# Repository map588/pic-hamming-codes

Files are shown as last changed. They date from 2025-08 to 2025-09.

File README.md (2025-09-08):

# PIC Parity Bit Error Detection Game

A PIC16F818 microcontroller-based educational game that teaches error detection using Hamming code parity bits through an interactive LED matrix display.

## Project Overview

This project implements a 4x4 LED grid game where players must identify and correct single-bit errors in transmitted data using parity bits. The system displays random data with intentional errors, and players use buttons to select and correct the flipped bit. 

I was inspired to make the project by [this excellant video](https://youtu.be/wTJI_WuZSwE?si=To3kZnW4QarjRsSB) by 3Blue1Brown on youtube.  Its really good, you should go watch it, its way better than my boring assembly code. 

### Key Features
- 4x4 LED matrix displaying random data patterns
- 4 parity bit indicators showing error detection codes
- Interactive button controls for bit selection and confirmation
- Visual feedback for correct/incorrect solutions
- Random number generation for varied gameplay

## Game Mechanics

1. **Display**: A 4x4 grid shows random on/off LEDs representing transmitted data
2. **Parity Bits**: 4 LEDs indicate parity for different bit groupings:
   - Bit 0: Columns 1 and 3 parity
   - Bit 1: Columns 2 and 4 parity  
   - Bit 2: Rows 1 and 3 parity
   - Bit 3: Rows 2 and 4 parity
3. **Objective**: Identify which bit in the 4x4 grid has been flipped
4. **Controls**:
   - Selection button: Cycle through grid positions (current selection blinks)
   - Confirm button: Lock in selection and check answer
   - Reset button: Generate new puzzle

### Feedback System
- **Correct Answer**: Diagonal checkmark animation on grid, all parity bits flash
- **Wrong Answer**: X pattern on grid, parity bits alternate

## Hardware

### Components
- **Microcontroller**: PIC16F818
- **Display**: 4x4 LED matrix + 4 parity indicator LEDs
- **Input**: 3 push buttons (select, confirm, reset)
- **Power**: Standard 5V supply

### Circuit Design
- Custom PCB design created in KiCad
- Surface-mount components for compact design
- ICSP programming header for development

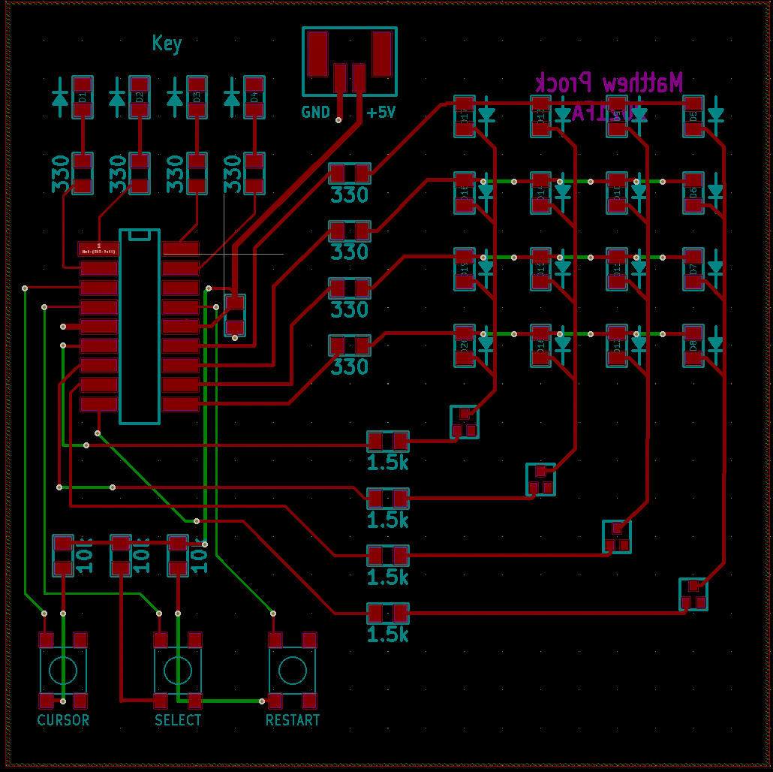
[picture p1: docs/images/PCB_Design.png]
PCB Design

*Custom PCB layout showing component placement and routing*

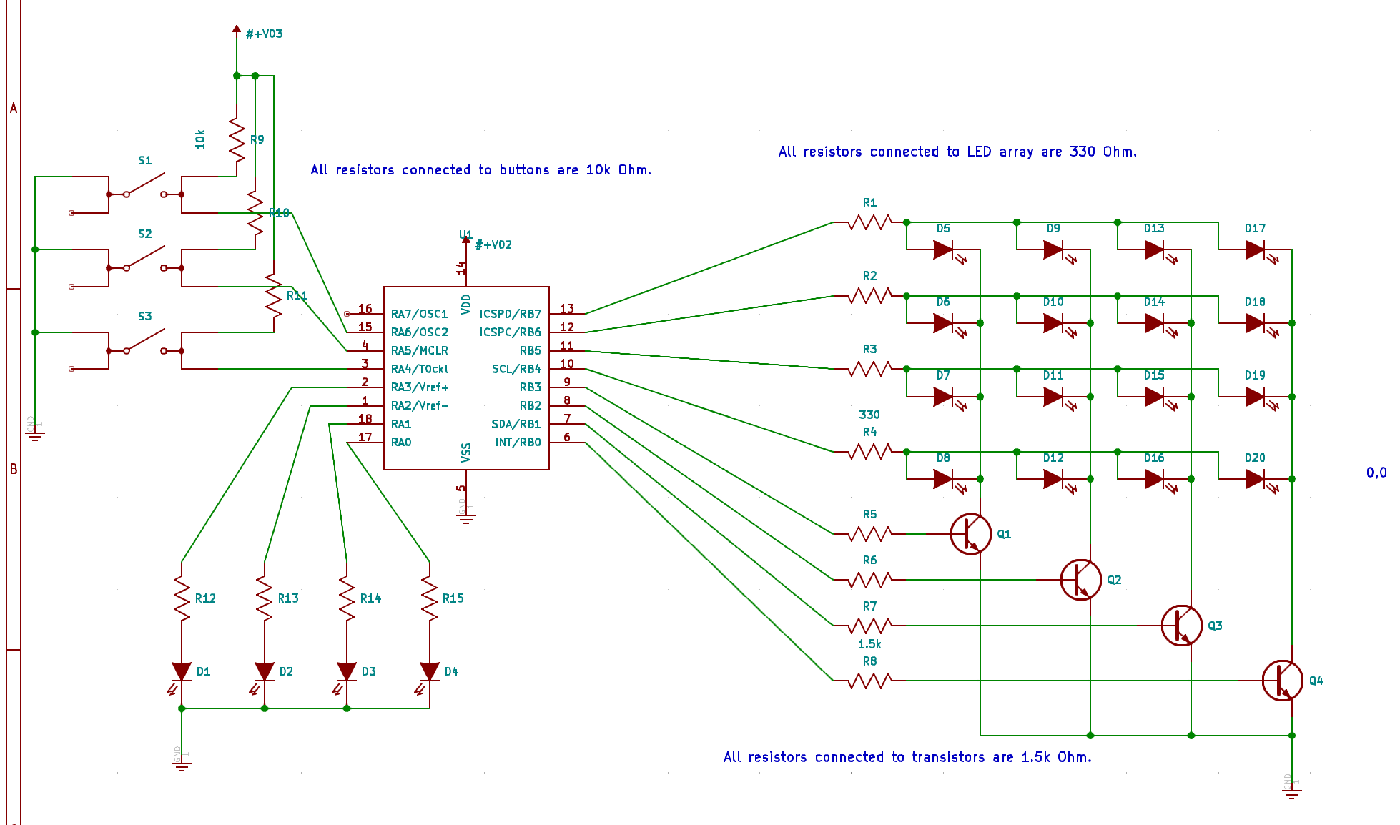
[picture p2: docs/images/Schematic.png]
Schematic
 
*Circuit schematic with PIC16F818 microcontroller and LED matrix*

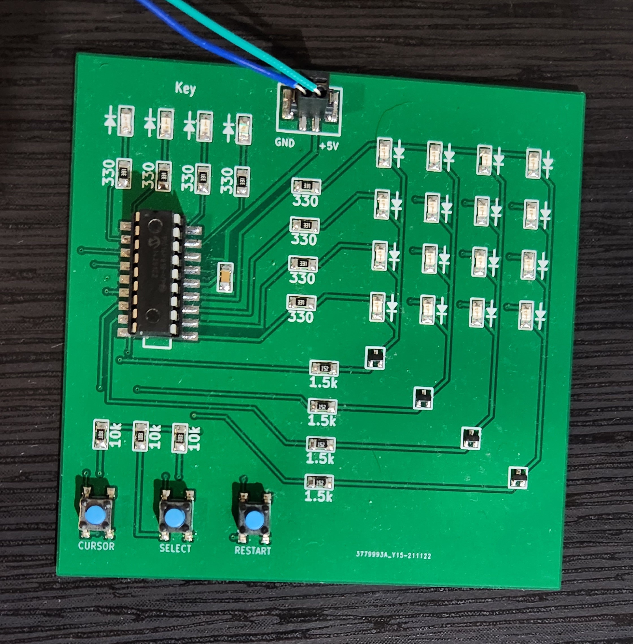
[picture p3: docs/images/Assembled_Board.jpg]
Assembled Board

*Final assembled PCB showing the completed hardware*

## Software

### Architecture
- **Language**: PIC Assembly (MPASM)
- **Random Number Generator**: X-ABC algorithm implementation
- **Interrupt Handling**: Button debouncing and timing
- **Display Control**: LED matrix multiplexing
- **Game Logic**: Hamming code parity calculation and verification

### Key Technical Challenges

#### Interrupt-Driven Display Multiplexing
The most complex aspect was implementing precise timer interrupt handling for LED matrix control:

- **8-bit Timer Interrupt**: With only an 8-bit timer, careful cycle counting was required to utilize the interrupt effectively 
- **Manual Context Switching**: PIC16F818 has no automatic stack - all register preservation (W, STATUS, FSR) must be handled manually in the ISR
- **Dual Display Timing**: The interrupt cycles through two 4x4 display boards, using an 8-pin indexing system
- **Memory Architecture**: 4 bytes per board (8 total), with MSB controlling row transistors and 4 LSBs selecting column LEDs
- **Persistence of Vision**: Timer frequency tuned so LEDs appear continuously lit despite sequential scanning
- **Input Responsiveness**: ISR timing balanced to maintain button polling responsiveness - if interrupts run too long, user input is missed

This required hours of timing analysis and empirical tuning to achieve both visual persistence and real-time user interaction.

#### Bit-by-Bit Board Traversal Edge Cases
The scan_routine implements a complex state machine for traversing the 4x4 board one bit at a time, with several critical edge cases:

- **Bit Position Tracking**: BITCOUNTER (0-3) tracks position within each row, while BITCHECK holds the actual bit mask being shifted left via `rlf` to traverse columns
- **Row Boundary Detection**: When BITCOUNTER reaches 4 (checked via `btfsc BITCOUNTER,2`), the end_row routine handles:
  - XORing the last bit of the current row
  - Incrementing FSR to move to the next row
  - Resetting BITCOUNTER to 0 and BITCHECK to 0x18 for the next row
- **Special First Bit Handling**: When BITCOUNTER is 0 (start of row), a different literal is XORed with the COPY board due to the boundary with the column bits 
- **ROWCHECK Wraparound**: ROWCHECK tracks the current row (0x24-0x27 for BOARDCPY), with bit 3 tested to detect when all 4 rows are complete, triggering a reset to the first row
- **Debounce Timing**: Each button press includes a delay (0xC0) to prevent multiple triggers from a single press while maintaining responsiveness

This state machine allows users to select any single bit in the 4x4 grid despite having only one selection button, by cycling through all 16 positions sequentially.

#### Automatic Board Swapping via Timer Interrupt
The system implements an elegant visual effect where two boards (BOARDPTR and BOARDCPY) are "automagically" swapped at human-visible intervals:

- **Timer-Driven Display**: TMR0 overflow triggers the interrupt service routine, which calls `display_both`
- **Asymmetric Display Timing**: 
  - BOARDPTR displays for 16 iterations (4 LEDs × 4 rows × 255 delay cycles)
  - BOARDCPY displays for 64 iterations (4× longer) to emphasize the modified state
  - This creates a visual "blink" effect where changes are clearly visible
- **Memory Layout**: Two consecutive 4-byte blocks in RAM:
  - BOARDPTR (0x20-0x23): Original puzzle state
  - BOARDCPY (0x24-0x27): User-modified state with bit flips
- **Multiplexed Column Driving**: PORTB drives transistor bases with patterns 0x08, 0x04, 0x02, 0x01 to enable each column sequentially
- **Human Persistence of Vision**: Cycling through all positions (faster than ~30Hz) makes both boards appear simultaneously lit with the modified bits appearing to blink

## Project Structure

```
├── hardware/
│   ├── pcb/              # KiCad PCB files
│   ├── schematics/       # Schematic designs
│   ├── gerbers/          # Manufacturing files
│   └── libraries/        # Custom component libraries
├── software/
│   ├── src/              # PIC assembly source code
├── docs/
│   ├── images/           # Project photos and screenshots
│   ├── datasheets/       # Component specifications
│   └── Final_Project_Idea.txt  # Original project concept
└── manufacturing/        # Production files
```

## License

This project is open source and available for educational use. The random number generator algorithm is freely available but not suitable for cryptographic applications.

---

*Developed as a final project demonstrating embedded systems design, PCB layout, and error detection algorithms.*

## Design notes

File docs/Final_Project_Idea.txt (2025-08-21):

Matthew Prock Final Project Idea

The idea is a 4x4 grid of LEDs that shows a random set of on and off LEDs, 4 LEDs to represent the parity bits for that data.  The idea is that a single bit has been flipped during transmission, and the game is to solve which bit has been flipped.  There will be a button to select which LED should be flipped, when its clicked the next bit will be selected and blink showing its the current selection.  There is another button to lock in the selection.  

If the player is right, the Board will flash in a "winning" kind of way,  whether its stripes moving diagonally, and the 4 LED key indicator will flash all 4 bits on and off.  If its wrong, there will be some kind of X or negative feedback on the whole board, and the key bar will alternate bits(0,2 then (1,3) etc.  The patterns are subject to change depending on how challenging they are, but it should be just a straight forward list of the pattern configurations.  

The first bit is columns 1 and 3 on the board, second is 2 and 3, third is rows 1 and 3, fourth is 2 and 3. 

The last button is to reset the game with a new board and key.

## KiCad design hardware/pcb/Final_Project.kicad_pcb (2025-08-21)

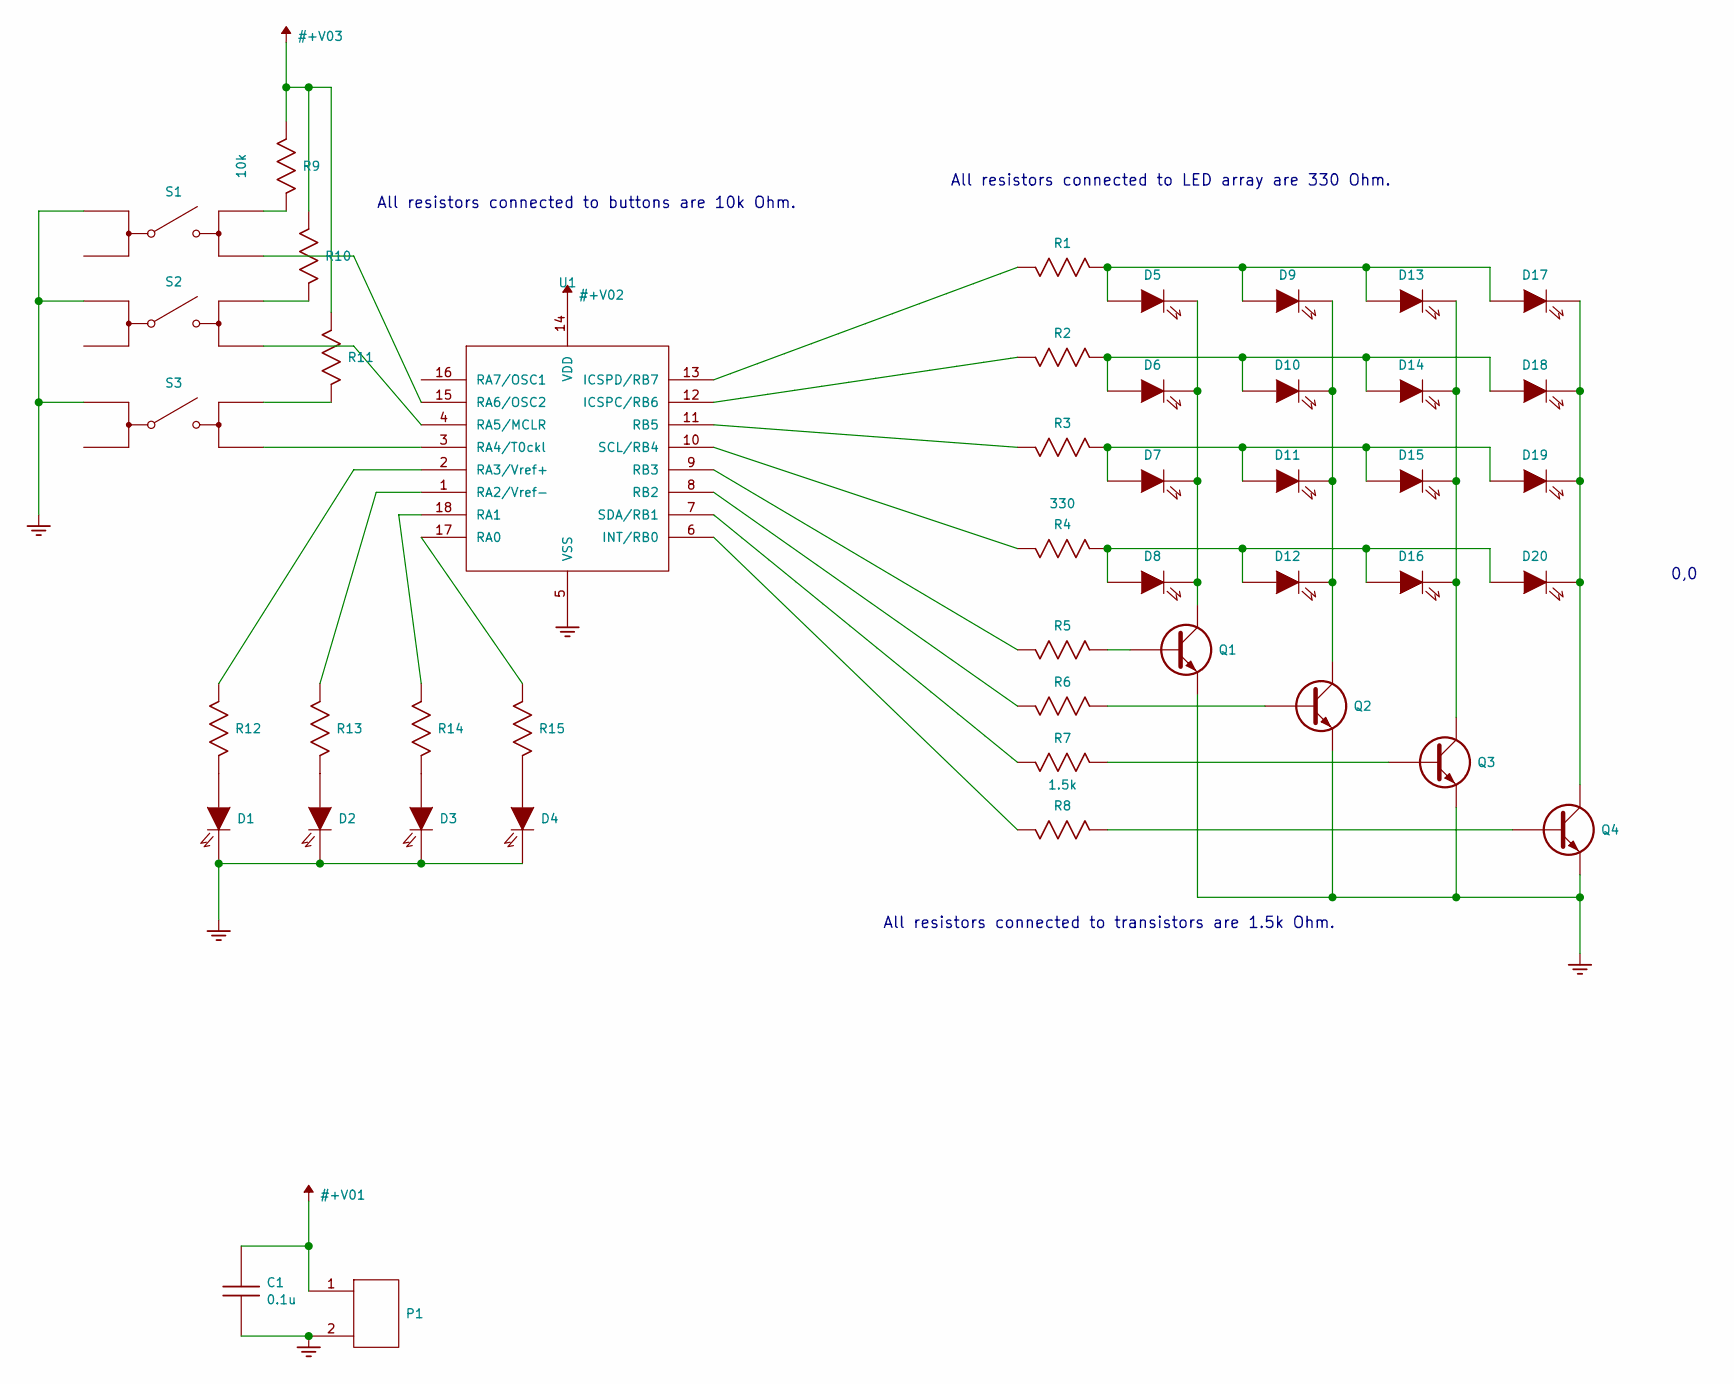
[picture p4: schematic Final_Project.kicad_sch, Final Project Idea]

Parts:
C1: 0.1u; SM1206
D1, D2, D3, D4, D5, D6, D7, D8, D9, D10, D11, D12, D13, D14, D15, D16, D17, D18, D19, D20: SVC_LED; SM1206-D_LED
P1: SVC_CONN_2PIN; 2-PIN-Power
Q1, Q2, Q3, Q4: SVC_Q_MMBT3904L; SOT23
R1, R2, R3, R4, R12, R13, R14, R15: 330; SM1206-R_C
R5, R6, R7, R8: 1.5k; SM1206-R_C
R9, R10, R11: 10k; SM1206-R_C
S1, S2, S3: SVC_BUTTON_SWITCH; BUTTON-SWITCH-SPST
U1: SVC_PIC16F818-18PDIP; SM_DIP18-300

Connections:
+V: C1.1, P1.1, R9.1, R10.1, R11.1, U1.14 (VDD)
GND: C1.2, D1.2 (K), D2.2 (K), D3.2 (K), D4.2 (K), P1.2 (PM), Q1.2 (E), Q2.2 (E), Q3.2 (E), Q4.2 (E), S1.3, S2.3, S3.3, U1.5 (VSS)
unnamed: D1.1 (A), R12.2
unnamed: D2.1 (A), R13.2
unnamed: D3.1 (A), R14.2
unnamed: D4.1 (A), R15.2
unnamed: D5.2 (K), D6.2 (K), D7.2 (K), D8.2 (K), Q1.3 (C)
unnamed: D6.1 (A), D10.1 (A), D14.1 (A), D18.1 (A), R2.1
unnamed: D9.2 (K), D10.2 (K), D11.2 (K), D12.2 (K), Q2.3 (C)
unnamed: D7.1 (A), D11.1 (A), D15.1 (A), D19.1 (A), R3.1
unnamed: D8.1 (A), D12.1 (A), D16.1 (A), D20.1 (A), R4.1
unnamed: D5.1 (A), D9.1 (A), D13.1 (A), D17.1 (A), R1.1
unnamed: D13.2 (K), D14.2 (K), D15.2 (K), D16.2 (K), Q3.3 (C)
unnamed: D17.2 (K), D18.2 (K), D19.2 (K), D20.2 (K), Q4.3 (C)
unnamed: Q1.1 (B), R5.1
unnamed: Q2.1 (B), R6.1
unnamed: Q3.1 (B), R7.1
unnamed: Q4.1 (B), R8.1
unnamed: R1.2, U1.13 (ICSPD/RB7)
unnamed: R2.2, U1.12 (ICSPC/RB6)
unnamed: R3.2, U1.11 (RB5)
unnamed: R4.2, U1.10 (SCL/RB4)
unnamed: R5.2, U1.9 (RB3)
unnamed: R6.2, U1.8 (RB2)
unnamed: R7.2, U1.7 (SDA/RB1)
unnamed: R8.2, U1.6 (INT/RB0)
unnamed: R9.2, S1.1
unnamed: R10.2, S2.1
unnamed: R11.2, S3.1
unnamed: R12.1, U1.2 (RA3/Vref+)
unnamed: R13.1, U1.1 (RA2/Vref-)
unnamed: R14.1, U1.18 (RA1)
unnamed: R15.1, U1.17 (RA0)
unnamed: S1.2, U1.15 (RA6/OSC2)
unnamed: S2.2, U1.4 (RA5/MCLR)
unnamed: S3.2, U1.3 (RA4/T0ckl)

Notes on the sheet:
All resistors connected to buttons are 10k Ohm.
All resistors connected to transistors are 1.5k Ohm.
All resistors connected to LED array are 330 Ohm.
0,0

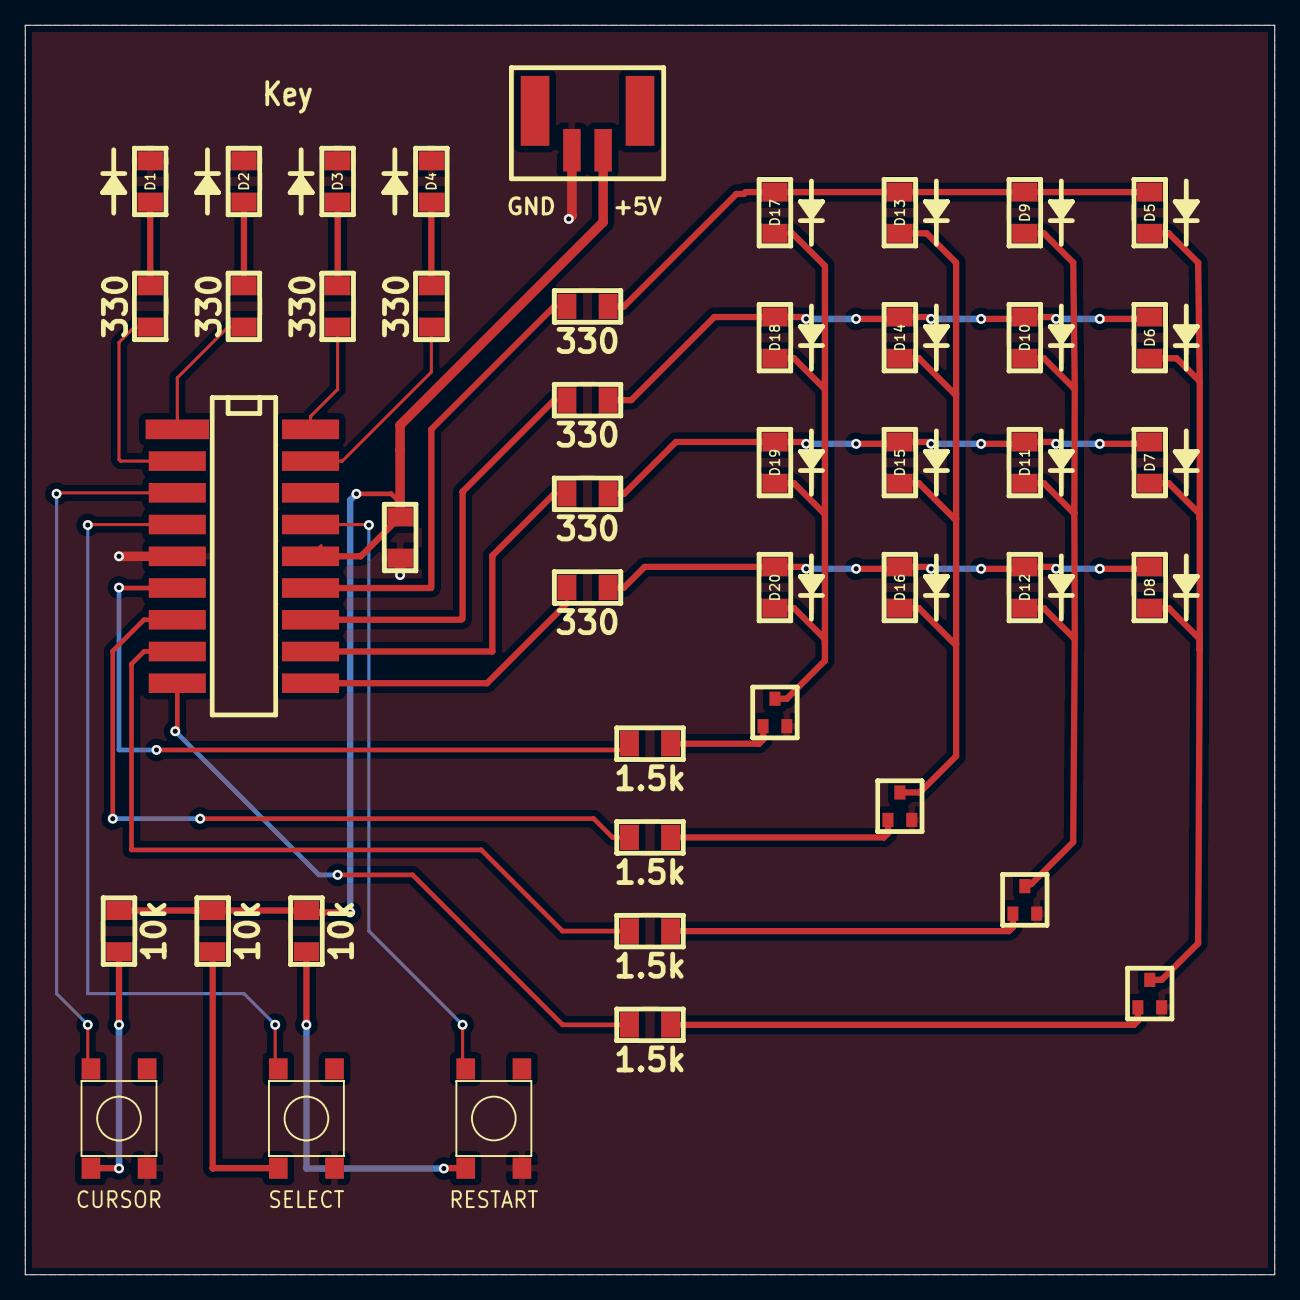
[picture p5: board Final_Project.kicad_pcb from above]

Board: 2 copper layers, 100.0 x 100.0 mm, 45 parts (0 on the bottom side), 36 nets.

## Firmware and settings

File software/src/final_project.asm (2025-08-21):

;**********************************************************************

	list      p=16f818           ; list directive to define processor
	#include <p16f818.inc>        ; processor specific variable definitions

	errorlevel  -302              ; suppress message 302 from list file

	__CONFIG   _CP_OFF & _WRT_ENABLE_OFF & _CPD_OFF & _CCP1_RB2 & _DEBUG_OFF & _LVP_OFF & _BODEN_OFF & _MCLR_OFF & _WDT_OFF & _PWRTE_ON & _INTRC_IO

	;//VARIABLES

fsr_temp equ 0x79
status_temp equ 0x7D
w_temp equ 0x7E

BITCHECK equ 0x7F
BITCOUNTER equ 0x7B
ROWCHECK equ 0x7C


BOARDPTR equ 0x20 ; [4]
BOARDCPY equ 0x24 ; [4]
STAGEPTR equ 0x28 ; [4]

RAND_XOR equ 0x2D
RAND_SHIFT equ 0x2E
RAND_TEMP equ 0x2F 

RAND_COUNTER=0x30
RAND_STATE=0x31

temp_board equ 0x40
temp_test equ 0x50
 
seed_1 equ 0x5A
seed_2 equ 0x5B
seed_3 equ 0x5C

temp equ 0x60
temp2 equ 0x61
temp3 equ 0x62
KEYA equ 0x63
KEYT equ 0x64

FLIPPEDBITPTR equ 0x70
ROWPTR equ 0x71
RANDPTR equ 0x72  ; [3]
special_check equ 0x7A

FLIPPEDBIT equ b'00001000'

PAR0   equ b'00000101' ; bits in col 1 & 3
PAR1   equ b'00000011' ; bits in col 2 & 3
PAR2   equ b'01011111' ; bits in row 1 & 3
PAR3   equ b'00111111' ; bits in row 2 & 3

INIT_0 equ b'11111000'
INIT_1 equ b'11110100'
INIT_2 equ b'11110010'
INIT_3 equ b'11110001'



	ORG     0x00             ; processor reset vector
	goto	main

irq	ORG	0x004
	movwf	w_temp		; store status reg, W, and PTR reg
	movf	 STATUS,0
	movwf	status_temp
	movf 	FSR,0
	movwf	fsr_temp

	bcf  INTCON,5   ; disable TMR0 interrupt to prevent recursion

	call display_both  ; display boards in irq


	btfss INTCON,2   ;check if overflow
	goto irq_finish 
	bcf  INTCON,2



	irq_finish
	bsf  INTCON,5   ; re-enable TMR0 interrupt
	movf	status_temp,0
	movwf	STATUS
	movf 	fsr_temp,0
	movwf	FSR
	swapf	w_temp,1
	swapf	w_temp,0
	retfie

main
	call init_board
	call init_patterns
	clrf RANDPTR
	clrf RANDPTR+1
	clrf RANDPTR+2
	call init_makerand
start
	call init_board
	call clock_init
	call port_init
	call irq_init
	banksel PORTB
	
	
	
	
start_loop	
	BTFSC PORTA,4  
	goto start_loop  ; wait for user to press select for entropy
	call make_rand   
	

	call format_rands 
	call copy_board


button_loop
	
	btfsc ROWCHECK,3 
	call rowcheck_reset 
	btfss PORTA,4
	call scan_routine
	btfss PORTA,5
	goto set_routine
	btfss PORTA,6
	goto start
	goto button_loop
	
	
scan_routine
	btfsc BITCOUNTER,2
	call end_row
	
	movf BITCHECK,0

	movf BITCOUNTER,1 ;moves file to itself to update status flag
	btfsc STATUS,2   ;if bitcounter is 0
	movf  special_check,0

	xorwf INDF,1
	rlf  BITCHECK    ;goes to next
	incf BITCOUNTER  ;adds, will cause behavior in button_loop if = 4

	movlw b'11000000'
	call delay
	return

set_routine		 ; user hit set, begin the correct check
	movlw BOARDCPY
	movwf FSR
	clrf temp
	clrf KEYT
	
row_loop
	MOVF  temp,0
	IORWF INDF,1
	INCF  FSR
	RRF   temp,1
	BTFSS temp,3
	goto row_loop

	MOVLW b'11110000'
	ANDWF PORTA,1
	MOVLW b'00001111'
	ANDWF RANDPTR+2,0
	MOVWF KEYA
	IORWF PORTA,1

	return


	
	movlw b'00001000'  ;blinks when routine is finished for debug
	xorwf PORTA,1
	return


rowcheck_reset
	movlw BOARDCPY
	movwf ROWCHECK
	movwf FSR
	return

end_row
	movlw b'00000001'   ;flips last bit of row
	xorwf INDF,1
	incf FSR            ;moves to next
	incf ROWCHECK       ;keeps track of row
	clrf BITCOUNTER     ;resets bit counter
	movlw b'00011000'   ;resets bit check
	movwf BITCHECK
	return
	
new_seed
	movf TMR0,0
	movwf seed_1
	rrf seed_1,1
	rrf seed_1,1
	xorwf seed_1,0
	movwf seed_2
	addlw b'00110011'
	movwf seed_3
	rlf seed_3,1
	return

init_makerand
	call new_seed
	movf RANDPTR,0
	xorwf seed_1,1
	movf RANDPTR+1,0
	xorwf seed_2,1
	movf RANDPTR+2,0
	xorwf seed_3,1
	
	movlw b'00110011'
	movwf temp
	
	movf RANDPTR,0
	xorwf RANDPTR+2,0
	xorwf temp,0
	movwf RANDPTR
	
	addwf RANDPTR+1,0
	movwf RANDPTR+1
	
	rrf RANDPTR+1,0
	xorwf RANDPTR,0
	addwf RANDPTR+2,1
	return
	
clear_board_cpy
	movlw BOARDCPY 
	movwf FSR
	call clr_INDF
	call clr_INDF
	call clr_INDF
	call clr_INDF
	return 

init_board
	movlw BOARDPTR
	movwf FSR
	movlw INIT_1
	call W_to_INDF
	movlw INIT_2
	call W_to_INDF
	movlw INIT_3
	call W_to_INDF
	movlw INIT_4
	call W_to_INDF
	
	call clear_board_cpy
	return
	
make_rand
	call new_seed
	incf temp
	movf RANDPTR,0
	xorwf RANDPTR+2,0
	xorwf temp,0
	movwf RANDPTR
	
	addwf RANDPTR+1,0
	movwf RANDPTR+1
	
	rrf RANDPTR+1,0
	xorwf RANDPTR,0
	addwf RANDPTR+2,1
	return
	
	
	

test0
	movlw BOARDCPY
	addwf temp,0
	movwf FSR
	movlw KEY0
	andwf INDF,0
	movwf temp_test
	movlw temp_board
	addwf temp,0
	movwf FSR
	movf temp_test,0
	movwf INDF
	incf temp
	btfss temp,2
	goto test0

	movlw temp_board
	movwf FSR

	movf INDF,0
	movwf temp_test

test0_loop
	movf INDF,0
	xorwf temp_test,1
	incf FSR
	btfss FSR,2
	goto test0_loop

	movf temp_test,0
	rrf  temp_test
	rrf  temp_test

	xorwf temp_test,1
	btfsc temp_test,0
	bsf   KEYT,3

	clrf temp

test1
	movlw BOARDCPY
	addwf temp,0
	movwf FSR
	movlw PAR1
	andwf INDF,0
	movwf temp_test
	movlw temp_board
	addwf temp,0
	movwf FSR
	movf temp_test,0
	movwf INDF
	incf temp
	btfss temp,2
	goto test1

	movlw temp_board
	movwf FSR

	movf INDF,0
	movwf temp_test

test1_loop
	movf INDF,0
	xorwf temp_test,1
	incf FSR
	btfss FSR,2
	goto test1_loop

	movf temp_test,0
	rrf  temp_test

	xorwf temp_test,1
	btfsc temp_test,0
	bsf   KEYT,2

	clrf temp

test2
	movlw BOARDCPY
	addwf temp,0
	movwf FSR
	movlw PAR2
	andwf INDF,0
	movwf temp_test
	movlw temp_board
	addwf temp,0
	movwf FSR
	movf temp_test,0
	movwf INDF
	incf temp
	btfss temp,2
	goto test2

	movlw temp_board
	movwf FSR

	movf INDF,0
	movwf temp_test

test2_loop
	movf INDF,0
	btfsc INDF,6
	xorwf temp_test,1
	btfsc INDF,4
	incf FSR
	btfss FSR,2
	goto test2_loop

	movf temp_test,0
	rrf  temp_test
	rrf  temp_test

	xorwf temp_test,1

	movf temp_test,0
	rrf  temp_test

	xorwf temp_test,1

	btfsc temp_test,0
	bsf   KEYT,1

	clrf temp

test3
	movlw BOARDCPY
	addwf temp,0
	movwf FSR
	movlw PAR3
	andwf INDF,0
	movwf temp_test
	movlw temp_board
	addwf temp,0
	movwf FSR
	movf temp_test,0
	movwf INDF
	incf temp
	btfss temp,2
	goto test3

	movlw temp_board
	movwf FSR

	movf INDF,0
	movwf temp_test

test3_loop
	movf INDF,0
	xorwf temp_test,1
	incf FSR
	btfss FSR,2
	goto test3_loop

	movf temp_test,0
	rrf  temp_test
	rrf  temp_test

	xorwf temp_test,1

	movf temp_test,0
	rrf  temp_test

	xorwf temp_test,1

	btfsc temp_test,0
	bsf   KEYT,0

	clrf temp

	movf KEYT,0
	xorwf KEYA,0

	btfsc STATUS,2
	goto stage_win

	goto stage_loss


WIN_1  equ b'01001000'
WIN_2  equ b'10000100'
WIN_3  equ b'01000010'
WIN_4  equ b'00010001' 

LOSS_1 equ b'10011000'
LOSS_2 equ b'01101100'
LOSS_3 equ b'01101010'
LOSS_4 equ b'10011001'



W_to_INDF
	movwf INDF
	incf FSR
	return

clr_INDF
	clrf INDF
	incf FSR
	return

stage_win
	movlw STAGEPTR 
	movwf FSR

	movlw WIN_1
	call W_to_INDF	
	movlw WIN_2
	call W_to_INDF
	movlw WIN_3
	call W_to_INDF
	movlw WIN_4
	call W_to_INDF
	goto end_game
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
